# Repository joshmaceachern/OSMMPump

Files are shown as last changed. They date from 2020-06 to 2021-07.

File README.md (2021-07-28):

# OSMMPump
Open-Source Multichannel Microfluidics Pump. Developed as a research project to create a system that can precisely deliver fluids at a resolution of up to 0.1 uL/min. 
This project uses a RAMPS 1.4 mainboard, and 5 NEMA 14 Stepper motors to drive the pumps. A full bill of materials is available under 'OSMM Pump BOM.ods'. 
All files should be 3D printable on a well-tuned FDM printer, however, final prints for my testing were done on an SLA machine. 

This work is licensed under a Creative Commons Attribution-Share Alike 4.0 International License((CC BY-SA 4.0)).
Learn more at https://creativecommons.org/licenses/by/4.0/

Like what I do? Buy me a coffee at https://ko-fi.com/joshmaceachern! This allows me to focus more of my time on developing stuff like this.

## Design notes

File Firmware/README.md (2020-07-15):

# Marlin2ForPipetBot 3D Printer and Lab Robot CNC Firmware
 
Additional documentation can be found in the 
repository [DerAndere1/Marlin at https://github.com](https://github.com/DerAndere1/Marlin/tree/Marlin2ForPipetBot) 
or on the [PipetBot-A8 project homepage](https://derandere.gitlab.io/pipetbot-a8) 
that is part of the [authors homepage](https://derandere.gitlab.io). 
For CNC machines with additional axes I, (J, (K)) that drive pumps or other tools,
e.g. lab robots (liquid handling robots, "pipetting robots"). 
Please test this firmware and let us know if it misbehaves in any way. 
Volunteers are standing by!

## Marlin2ForPipetBot Branch

__Not for production use. Use with caution!__

Marlin2forPipetBot is a branch of the Marlin fork by DerAndere (based on 
https://github.com/MarlinFirmware/Marlin/commit/ee7558a6228747a7502ab50e2817234fb8a6feb4 ). 

This branch is for patches to the latest Marlin2ForPipetBot release version.

Marlin2ForPipetBot supports up to six non-extruder axes (NON_E_AXES) plus 
extruders (XYZIJK + E). 
Currently, only a subset of the Marlin G-code dialect is supported:

- G1, G28, G90, G91, G92 (partially) 
- M17, M18, M43, M85, M114 (partially), M206 (partially), M500, M501, M502

Axis names are:

| NON_E_AXES | Axis codes |
|---|---|
| 3|X, Y, Z, E |
| 4|X, Y, Z, I, E |
| 5|X, Y, Z, I, J, E |
| 6|X, Y, Z, I, J, K, E|

Example syntax for movement (G-code G1) with NON_E_AXES 6: 
```
G1 [Xx.xxxx] [Yy.yyyy] [Zz.zzzz] [Ii.iiii] [Jj.jjjj] [Kk.kkkk] [Ee.eeee] [Ff.ffff]
```

## Building Marlin2ForPipetBot

To build Marlin2ForPipetBot you'll need [PlatformIO](http://docs.platformio.org/en/latest/ide.html#platformio-ide). The MarlinFirmware team has posted detailed instructions on [Building Marlin with PlatformIO](https://marlinfw.org/docs/basics/install_platformio.html).

## Hardware Abstraction Layer (HAL)

Marlin 2.0 introduces a layer of abstraction so that all the existing high-level code can be built for 32-bit platforms while still retaining full 8-bit AVR compatibility. Retaining AVR compatibility and a single code-base is important to us, because we want to make sure that features and patches get as much testing and attention as possible, and that all platforms always benefit from the latest improvements.

### Current HALs

  name|processor|speed|flash|sram|logic|fpu
  ----|---------|-----|-----|----|-----|---
  [Arduino AVR](https://www.arduino.cc/)|ATmega, ATTiny, etc.|16-20MHz|64-256k|2-16k|5V|no
  [Teensy++ 2.0](http://www.microchip.com/wwwproducts/en/AT90USB1286)|[AT90USB1286](http://www.microchip.com/wwwproducts/en/AT90USB1286)|16MHz|128k|8k|5V|no
  [Arduino STM32](https://github.com/rogerclarkmelbourne/Arduino_STM32)|[STM32F1](https://www.st.com/en/microcontrollers-microprocessors/stm32f103.html) ARM-Cortex M3|72MHz|256-512k|48-64k|3.3V|no
  [Due](https://www.arduino.cc/en/Guide/ArduinoDue), [RAMPS-FD](http://www.reprap.org/wiki/RAMPS-FD), etc.|[SAM3X8E ARM-Cortex M3](http://www.microchip.com/wwwproducts/en/ATsam3x8e)|84MHz|512k|64+32k|3.3V|no
  [Re-ARM](https://www.kickstarter.com/projects/1245051645/re-arm-for-ramps-simple-32-bit-upgrade)|[LPC1768 ARM-Cortex M3](http://www.nxp.com/products/microcontrollers-and-processors/arm-based-processors-and-mcus/lpc-cortex-m-mcus/lpc1700-cortex-m3/512kb-flash-64kb-sram-ethernet-usb-lqfp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)|100MHz|512k|32+16+16k|3.3-5V|no
  [MKS SBASE](http://forums.reprap.org/read.php?13,499322)|LPC1768 ARM-Cortex M3|100MHz|512k|32+16+16k|3.3-5V|no
  [Azteeg X5 GT](https://www.panucatt.com/azteeg_X5_GT_reprap_3d_printer_controller_p/ax5gt.htm)|LPC1769 ARM-Cortex M3|120MHz|512k|32+16+16k|3.3-5V|no
  [Selena Compact](https://github.com/Ales2-k/Selena)|LPC1768 ARM-Cortex M3|100MHz|512k|32+16+16k|3.3-5V|no
  [Teensy 3.5](https://www.pjrc.com/store/teensy35.html)|ARM-Cortex M4|120MHz|512k|192k|3.3-5V|yes
  [Teensy 3.6](https://www.pjrc.com/store/teensy36.html)|ARM-Cortex M4|180MHz|1M|256k|3.3V|yes

### HALs in Development

  name|processor|speed|flash|sram|logic|fpu
  ----|---------|-----|-----|----|-----|---
  [STEVAL-3DP001V1](http://www.st.com/en/evaluation-tools/steval-3dp001v1.html)|[STM32F401VE Arm-Cortex M4](http://www.st.com/en/microcontrollers/stm32f401ve.html)|84MHz|512k|64+32k|3.3-5V|yes
  [Smoothieboard](http://reprap.org/wiki/Smoothieboard)|LPC1769 ARM-Cortex M3|120MHz|512k|64k|3.3-5V|no
  [Adafruit Grand Central M4](https://www.adafruit.com/product/4064)|ARM-Cortex M4|120MHz|1M|256k|3.3V|yes

## Submitting Patches

Proposed patches should be submitted as a Pull Request against the [Marlin2ForPipetBot](https://github.com/MarlinFirmware/Marlin/tree/Marlin2ForPipetBot) branch.

- This branch is for fixing bugs and integrating any new features for the duration of the Marlin 2.0.x life-cycle.
- Follow the [Coding Standards](http://marlinfw.org/docs/development/coding_standards.html) to gain points with the maintainers.
- Please submit your questions and concerns to the [Issue Queue](https://github.com/DerAndere1/Marlin/issues).

### [RepRap.org Wiki Page](http://reprap.org/wiki/Marlin)

## Credits

The current Marlin dev team consists of:

 - Scott Lahteine [[@thinkyhead](https://github.com/thinkyhead)] - USA &nbsp; 
 - Roxanne Neufeld [[@Roxy-3D](https://github.com/Roxy-3D)] - USA
 - Bob Kuhn [[@Bob-the-Kuhn](https://github.com/Bob-the-Kuhn)] - USA
 - Chris Pepper [[@p3p](https://github.com/p3p)] - UK
 - João Brazio [[@jbrazio](https://github.com/jbrazio)] - Portugal
 - Erik van der Zalm [[@ErikZalm](https://github.com/ErikZalm)] - Netherlands &nbsp; 

Marlin2ForPipetBot is modified by:

 - DerAndere [[@DerAndere1](https://github.com/DerAndere1)] - Germany
 - Garbriel Beraldo [@GabrielBeraldo](https://github.com/GabrielBeraldo)] - Brasil
 - Olivier Briand [@hobiseven](https://github.com/hobiseven)] - Undisclosed

## License

Marlin2ForPipetBot is published under the [GPL license](https://github.com/DerAndere1/Marlin/blob/Marlin2ForPipetBot/LICENSE) because we believe in open development. The GPL comes with both rights and obligations. Whether you use Marlin firmware as the driver for your open or closed-source product, you must keep Marlin open, and you must provide your compatible Marlin source code to end users upon request. The most straightforward way to comply with the Marlin license is to make a fork of Marlin on Github, perform your modifications, and direct users to your modified fork.

While we can't prevent the use of this code in products (3D printers, CNC, etc.) that are closed source or crippled by a patent, we would prefer that you choose another firmware or, better yet, make your own.

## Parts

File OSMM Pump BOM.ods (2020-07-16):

OSMM Pump Bill of Materials
Pre-Fabricated Parts | Quantity | Source | Cost per unit | Total Cost | Comments
RAMPS 1.4 shield | 1 | https://www.aliexpress.com/item/32964178488.html | $3.03 | $3.03
Arduino Mega | 1 | https://www.amazon.com/ELEGOO-ATmega2560-ATMEGA16U2-Projects-Compliant/dp/B01H4ZLZLQ | $15.99 | $15.99
A4988 Stepper Drivers | 5 | https://www.aliexpress.com/item/32965199683.html | $0.60 | $3.00
ReprapDiscount full graphic smart controller | 1 | https://www.aliexpress.com/item/33008632717.html | $10.99 | $10.99
12V Power Supply | 1 | https://www.amazon.com/eTopxizu-Universal-Regulated-Switching-Computer/dp/B00D7CWSCG | $18.95 | $18.95 | This is very much overkill for this project, but I had one laying around. Any 12V DC power supply will do.
IEC Socket | 1 | https://www.amazon.com/BIQU-Rocker-Switch-Socket-Module/dp/B07KS2TQ45 | $8.99 | $8.99 | Only necessary if you're using a DC power supply you have to wire yourself(like I did). Not necessarily necessary if you use a wall wart.
NEMA 14 Stepper Motors | 5 | https://www.omc-stepperonline.com/nema-14-stepper-motor/nema-14-bipolar-1-8deg-23ncm-32-6oz-in-0-5a-7-5v-35x35x42mm-4-wires.html | $11.37 | $56.85
5mm x 36mm Steel Pin | 1 | https://www.mcmaster.com/91595A380/ | $13.63 | $13.63 | You will need 5 of these, but this is a 25-pack
3/32" x 1" steel pin | 1 | https://www.mcmaster.com/98381A443/ | $6.11 | $6.11 | You will need 15-30 of these, but this is a 50-pack.
#4 Screw Spacer | 1 | https://www.mcmaster.com/94639A714/ | $10.60 | $10.60 | You will need 15-30 of these, but this is a 100-pack.
Silicone Tubing(1/32" ID, 5/32" OD) | 5 | https://www.mcmaster.com/9628T54/ | $1.66 | $8.30 | 5 feet is the smallest roll McMaster has available.
M3 Screws | 1 | https://www.amazon.com/Sutemribor-320Pcs-Stainless-Button-Assortment/dp/B07CYNKLT2 | $10.99 | $10.99
3D Printed Parts
Healical Gear (10R@35.00) | 5
Healical Gear (30L@35.00) | 5
Motor Mount | 5
Pump Cover | 5
Roller Holder | 5
Electronics Body | 1 |  |  |  | This is for the overall electronics case
Electronics Platform | 1 |  |  |  | This is for the overall electronics case
Electronics Lid | 1 |  |  |  | This is for the overall electronics case
Optional Parts
Ball and Socket Connectors
Dupont Crimper/Crimps
40 mm fans | 1 | https://www.amazon.com/ANVISION-Bearing-Brushless-Cooling-YDM4010B12/dp/B0711FVD48 | 11.98 | 11.98

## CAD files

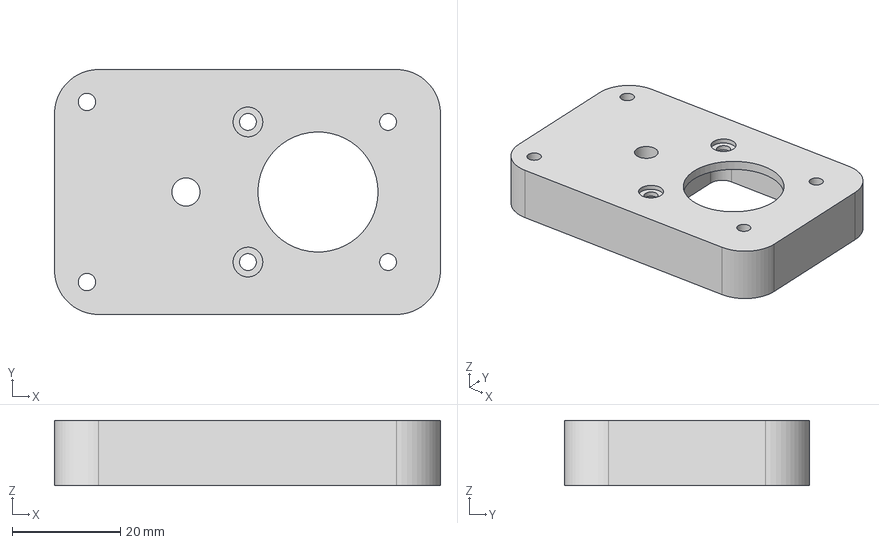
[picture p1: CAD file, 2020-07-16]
Design Files/Step Files/Motor Mount.step
71.4 x 45.3 x 12.0 mm

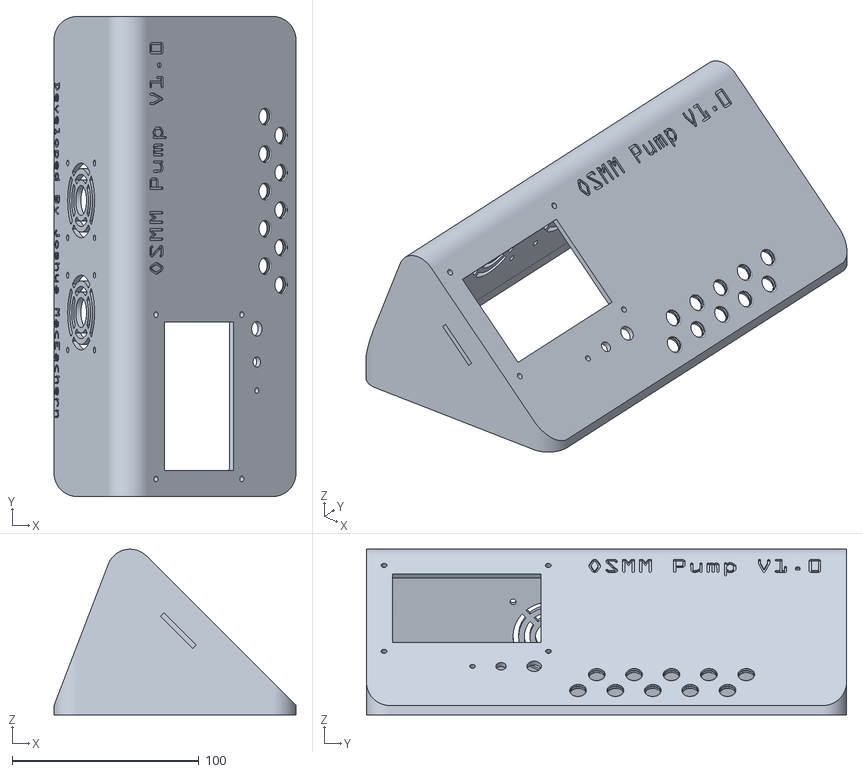
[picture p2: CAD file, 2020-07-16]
Design Files/STL Files/Electronics Lid.stl
129.5 x 256.9 x 88.6

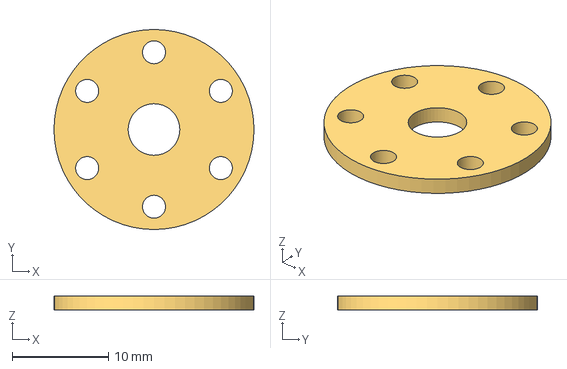
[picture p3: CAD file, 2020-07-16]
Design Files/Step Files/Roller Holder.step
20.8 x 20.8 x 1.50 mm

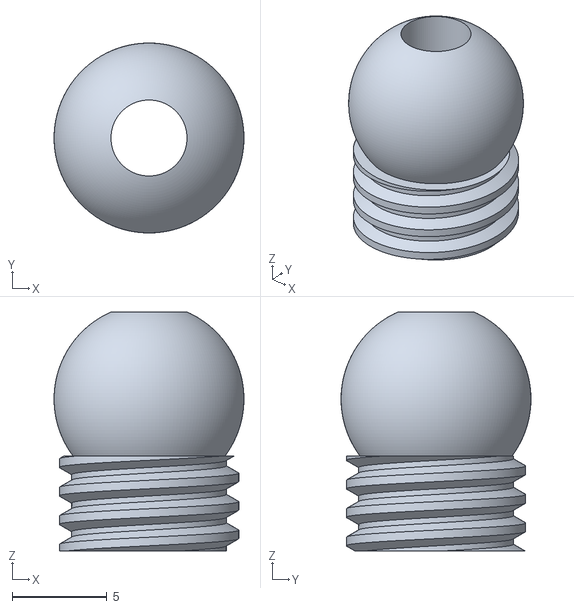
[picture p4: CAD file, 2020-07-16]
Design Files/STL Files/BS_Threaded Mount.stl
10.00 x 10.00 x 12.6

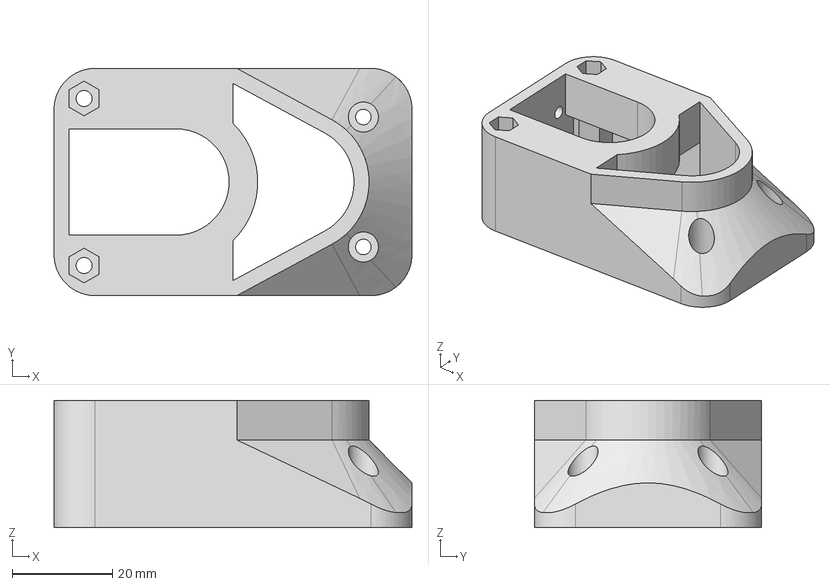
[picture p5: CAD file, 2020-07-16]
Design Files/Step Files/Pump Cover.step
71.4 x 45.3 x 25.4 mm

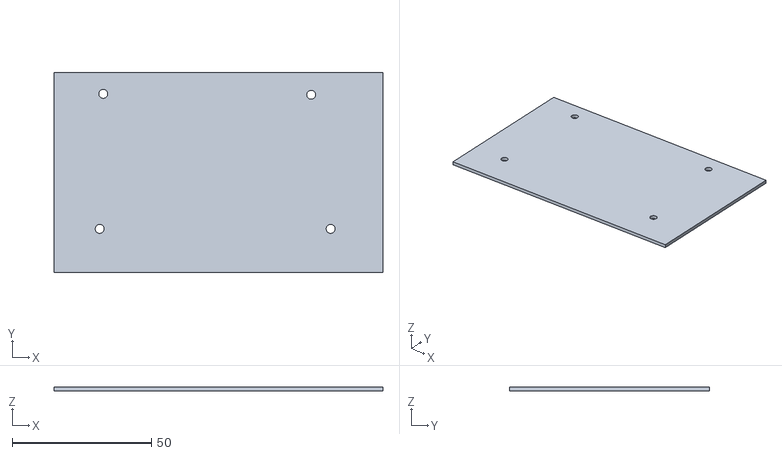
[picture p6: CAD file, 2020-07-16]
Design Files/STL Files/Electronics Platform.stl
118.2 x 71.8 x 1.50

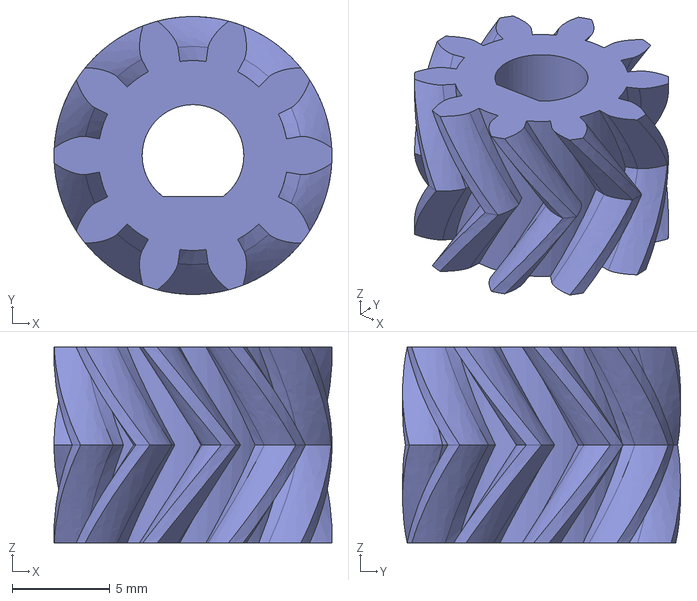
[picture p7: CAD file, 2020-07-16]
Design Files/Step Files/Healical Gear (10R@35.00).step
14.2 x 14.2 x 10.0 mm

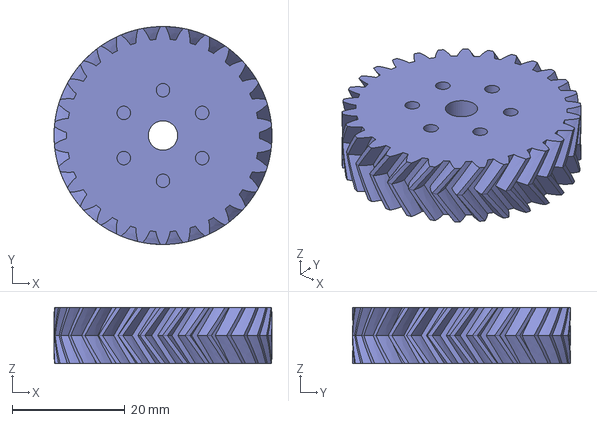
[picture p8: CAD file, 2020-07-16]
Design Files/Step Files/Healical Gear (30L@35.00).step
38.6 x 38.6 x 10.0 mm

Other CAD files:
Design Files/Step Files/Healical Gear (10R@35.00)_Pinion.step
Design Files/STL Files/Healical Gear (10R@35.00).stl
Design Files/STL Files/Healical Gear (30L@35.00).stl
Design Files/STL Files/Motor Mount.stl
Design Files/STL Files/Pump Cover.stl
Design Files/STL Files/Roller Holder.stl

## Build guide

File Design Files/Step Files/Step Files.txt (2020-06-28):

This folder contains step files fo all components in the design

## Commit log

2020-06-02 Added v2 of geared peristaltic pump system
    Uploaded v2 of the pump module. Each pump should be a self-contained unit when this is complete. Still need to fix issues with the tubing being too thick/stiff for this purpose. Will possibly switch to silicone
2020-06-16 Added gcode creator script
    Gcode creator script was added for use with Octave/Matlab. Takes motor volumes/flow rate and creates a gcode file from them. Also allows appending/replacing the gcode.
2020-06-16 Fixed flow rate input
    Added input/warnings for flow rate addition
2020-06-19 Added generic solid files
    Added .zip files containing both STEP and STL files for use with any given software.
2020-06-25 General Update/New code
    General design update, with minor fix issues. Added in rollers to reduce friction from the pins on the hose. This is represented by a new parameter in the F3d file. The rollers currently being used are nylon spacers for a #4 screw, as they are readily available.
    The Steps per uL calculator was also created. This takes the hose dimensions, and pump dimensions such as the hose bend radius and outputs what the steps/mm should be.
    Next steps are getting the Marlin fork to work to support five "axes"
2020-06-28 Create Stl files.txt
2020-06-28 Uploaded STL files
    REORG // Re-upload of stl files to have an actually organized github repository
    [Healical Gear (10R@35.00).stl, Healical Gear (30L@35.00).stl, Motor Mount.stl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]
2020-06-28 Uploaded Step files of all relevant components
    REORG//Re-upload of step files to have an organized repository
    [Healical Gear (10R@35.00)_Pinion.step, Healical Gear (30L@35.00).step, Motor Mount.step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]
2020-07-11 Add Script to generate gCode from flow rates instead of volumes
    New script has interface to generate gcode based on duration and flow rate of each individual pump, rather than volume and total flow rate.
2020-07-11 Minor ui tweak to flow rate gcode creator
2020-07-15 Create Marlin
2020-07-15 Working on uploading Marlin 2
2020-07-15 Uploaded Firmware
    Uploaded Marlin 2.0 firmware for use with RAMPS boards and the OSMM pump. Strongly based on the Marlin 2 for PipetBot by DerAndere.
2020-07-16 Update to .step files
    Minor design tweaks for better performance
    [Healical Gear (10R@35.00).step, Healical Gear (30L@35.00).step, Motor Mount.step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]
2020-07-16 Updated .stl files
    Minor Design tweaks for improved performance
    [BS_Threaded Mount.stl, Electronics Lid.stl, Electronics Platform.stl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]
2020-07-16 Added Bill of Materials
    [OSMM Pump BOM.ods]
